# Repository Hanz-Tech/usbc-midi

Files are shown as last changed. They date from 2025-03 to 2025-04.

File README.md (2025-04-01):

# Portable USB-MIDI-CV Converter

Ultraportable device for converting MIDI between various hardware standard

Allows you to convert signal between MIDI USB Device, MIDI USB host, MIDI TRS and CV.

## Features
* 1x1 MIDI TRS interface
* Tiny footprint (3cm x 3cm x 1cm)
* USB-C powered
* MIDI USB-MIDI compliant Device
* Plug and play - no drivers needed
* Can act USB host for USB MIDI keyboards, synths....
* Optoisolated TRS MIDI input
* Buffered TRS MIDI output
* CV (0-5 V)
* Powered by RP2040

## Photos

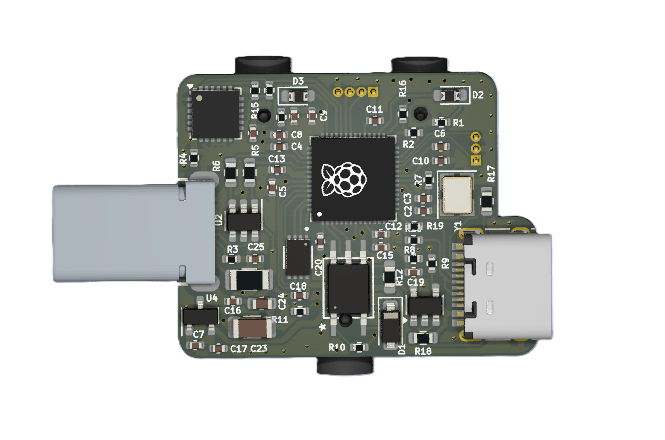
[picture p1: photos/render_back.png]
render


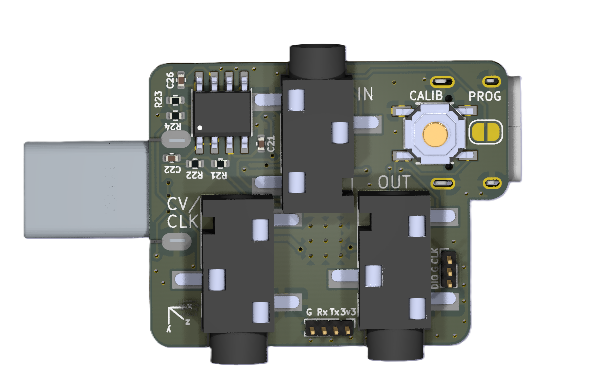
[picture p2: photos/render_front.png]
render


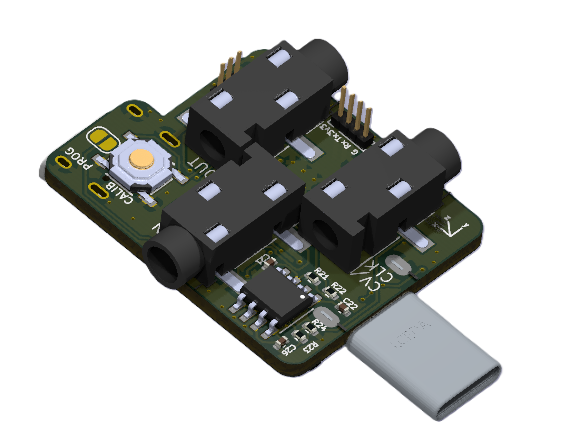
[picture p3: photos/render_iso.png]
render


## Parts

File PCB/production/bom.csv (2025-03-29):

Designator | Footprint | Quantity | Value | LCSC Part #
C1, C10, C11, C12, C13, C14, C15, C18, C25, C5, C6, C9 | 0402 | 12 | 100nF | C1525
C16, C17, C4, C8 | 0402 | 4 | 1uF | C52923
C19, C20, C26 | 0402 | 3 | 0.1uF | C1525
C2, C3 | 0402 | 2 | 22pF | C1555
C21, C22 | 0402 | 2 | 1nF | C1523
C23 | 1206 | 1 | 100uF | C15008
C24 | 0603 | 1 | 10uF | C19702
C7 | 0402 | 1 | 10uF | C15525
D1 | D_SOD-123 | 1 | 1N4148W | C81598
D2, D3 | 0603 | 2 | LED | C2286
F1 | 1206 | 1 | 500mA | C70077
J2 | PinHeader_1x03_P1.00mm_Vertical | 1 | 640456-3 | 640456-3
J5 | PinHeader_1x04_P1.00mm_Vertical | 1 | B4B-PH-K-S_LF__SN_ | B4B-PH-K-S(LF)(SN)
J6 | USB_C_Receptacle_HRO_TYPE-C-31-M-12 | 1 | USB_C_Receptacle_USB2.0_14P | C165948
R1, R10, R13, R8, R9 | 0402 | 5 | 220 | C25091
R11, R7 | 0402 | 2 | 1k | C11702
R12 | 0603 | 1 | 470 | C17710
R14, R15, R23, R3, R4 | 0402 | 5 | 5k1 | C25905
R16, R2, R24 | 0402 | 3 | 10k | C25744
R17, R18 | 0603 | 2 | 56k | C23206
R19, R20 | 0402 | 2 | 22 | C25092
R21, R22 | 0402 | 2 | 16k | C25759
R5, R6 | 0603 | 2 | 27R | C25190
S1 | TACTILE_SWITCH_SMD_5.2MM | 1 | TS-1187A-B-A-B | C318884
U1 | InvenSense_QFN-24_4x4mm_P0.5mm | 1 | MPU-6050 | C24112
U2 | SOT-23-6 | 1 | USBLC6-2SC6 | C2827654
U3 | RP2040-QFN-56 | 1 | RP2040 | C2040
U4 | SOT-23 | 1 | XC6206PxxxMR-Regulator_Linear | C5446
U5 | SOT-23-5 | 1 | SN74LVC1G07DBVR | C7829
U6 | W25Q16JVUXIQ | 1 | W25Q16JVUXIQ TR | C2843335
U7 | tlp2362 | 1 | TLP2362TPR_E | C37658
U8 | SOIC127P599X175-8N | 1 | OPA2335AIDR | C41618
UNK1 | USB-C-SMD_XKB_U261-24XN-4BC2SS | 1 | USB-C-SMD_XKB_U261-24XN-4BC2SS | C2938597
Y1 | Crystal_SMD_3225-4Pin_3.2x2.5mm | 1 | 12MHz | C9002

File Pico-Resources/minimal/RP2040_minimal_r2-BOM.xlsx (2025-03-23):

RP2040_minimal_r2 BOM
Item | Quantity | Reference | Part | Voltage | Current | Power | Material | Size | Tolerance | Manufacturer | Manuf. Part # | Description | Notes
1 | 3 | C1,C4,C17 | 10u | 16V |  |  | X5R | 0805_2012Metric | 10% | Murata | GRM21BR61C106KE15K | CAP CER 10UF 16V X5R 0805 | Or equivalent
2 | 2 | C2, C3 | 15p | 50V |  |  | C0G | 0402_1005Metric | 5% | Murata | GCM1555C1H150JA16D | CAP CER 15PF 50V C0G/NP0 0402 | Or equivalent
3 | 10 | C5, C6, C7, C9, C11, C12, C13, C14, C15, C16 | 100n | 25V |  |  | X7R | 0402_1005Metric | 10% | Murata | GRM155R71E104KE14J | CAP CER 0.1UF 25V X7R 0402 | Or equivalent
4 | 2 | C8, C10 | 1u | 10V |  |  | X6S | 0402_1005Metric | 10% | Murata | GRM155C81A105KA12D | CAP CER 1UF 10V X6S 0402 | Or equivalent
5 | 1 | J1 | USB_B_Micro |  |  |  |  |  |  | Amphenol | 10103594-0001LF | CONN RCPT USB2.0 MICRO B SMD R/A | Or equivalent
6 | 1 | J2 | 1x2 way header |  |  |  |  |  |  | Samtec | TSW-102-23-T-S | 2.54mm pin header 1x2 | Or equivalent
7 | 2 | J3, J4 | 2x18 way header |  |  |  |  |  |  | Samtec | TSW-118-23-T-D | 2.54mm pin header 2x18 | Or equivalent
8 | 2 | R1, R5 | 1k |  |  | 63mW |  | 0402_1005Metric | 1% | Yageo | RC0402FR-071KP | RES SMD 1K OHM 1% 1/16W 0402 | Or equivalent
9 | 1 | R2 | DNF |  |  |  |  | 0402_1005Metric |  |  |  |  | Do Not Fit
10 | 2 | R3, R4 | 27.4 |  |  | 63mW |  | 0402_1005Metric | 1% | Yageo | RC0402FR-0727R4L | RES SMD 27.4 OHM 1% 1/16W 0402 | Or equivalent
11 | 1 | U1 | NCP1117-3.3 |  |  |  |  | SOT-223-3 |  | ON Semiconductor | NCP1117ST33T3G | IC REG LINEAR 3.3V 1A SOT223
12 | 1 | U2 | W25Q128JVS |  |  |  |  | SOIC-8 |  | Winbond | W25Q128JVSIQ TR | IC FLASH 128M SPI 133MHZ 8SOIC
13 | 1 | U3 | RP2040 |  |  |  |  | QFN56 |  | Raspberry Pi | RP2040
14 | 1 | Y1 | ABM8-272-T3 |  |  |  |  | SMD_3225 |  | Abracon | ABM8-272-T3 | CRYSTAL 12.0000MHZ 3.2x2.5MM SMD

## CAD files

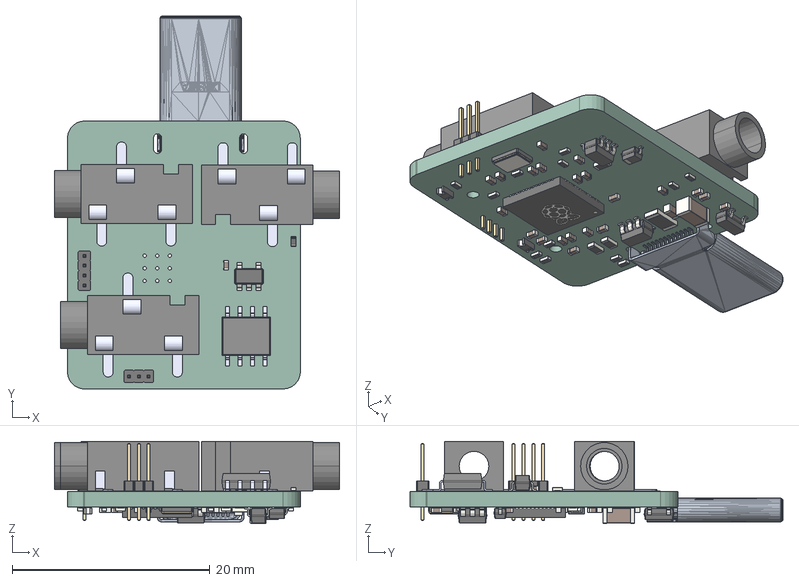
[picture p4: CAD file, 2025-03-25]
PCB/usbc_midi.step
28.9 x 37.7 x 8.30 mm
SOT_23_5 x 2
R_0402_1005Metric x 13
PinHeader_1x03_P100mm_Vertical
PJ-320B x 3
PinHeader_1x04_P100mm_Vertical
C_0402_1005Metric x 22
MCP6242T-E_SN
D_0603 x 2
SOT_23
R_0603_1608Metric x 3
C_1206_3216Metric
SOT_23_6
D_SOD_323
C_0603_1608Metric
Fuse_1206_3216Metric
RP2040_QFN_PACKAGE
Crystal_SMD_3225-4Pin_3.2x2.5mm
USB_C_SMD_XKB_U261_24XN_4BC2SS001
_autosave-usbc_midi_PCB

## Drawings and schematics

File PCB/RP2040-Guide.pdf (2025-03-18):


1 GPIO8 11 GPIO9 12 GPIO10 13 GPIO11 14 GPIO12 15 GPIO13 16 GPIO14 17 GPIO15 18 TESTEN 19 GPIO0 2 XTAL_IN 20 XTAL_OUT 21 SWCLK 24 SWDIO 25 ~{RUN} 26 GPIO16 27 GPIO17 28 GPIO18 29 GPIO1 3 GPIO19 30 GPIO20 31 GPIO21 32 GPIO22 34 GPIO23 35 GPIO24 36 GPIO25 37 GPIO26/ADC0 38 GPIO27/ADC1 39 GPIO2 4 GPIO28/ADC2 40 GPIO29/ADC3 41 ADC_AVDD 43 VREG_VIN 44 VREG_VOUT 45 D- 46 D+ 47 USB_VDD 48 GPIO3 5 DVDD 50 QSPI_SD3 51 QSPI_SCLK 52 QSPI_SD0 53 QSPI_SD2 54 QSPI_SD1 55 QSPI_SS_N 56 GND 57 GPIO4 6 GPIO5 7 GPIO6 8 GPIO7 9 U3 GND RP2040 +3.3V C6

File: RP2040-Guide.kicad_sch Sheet: / Sleepdealer

Id: 1/1 Title: RP2040 - Design Guide

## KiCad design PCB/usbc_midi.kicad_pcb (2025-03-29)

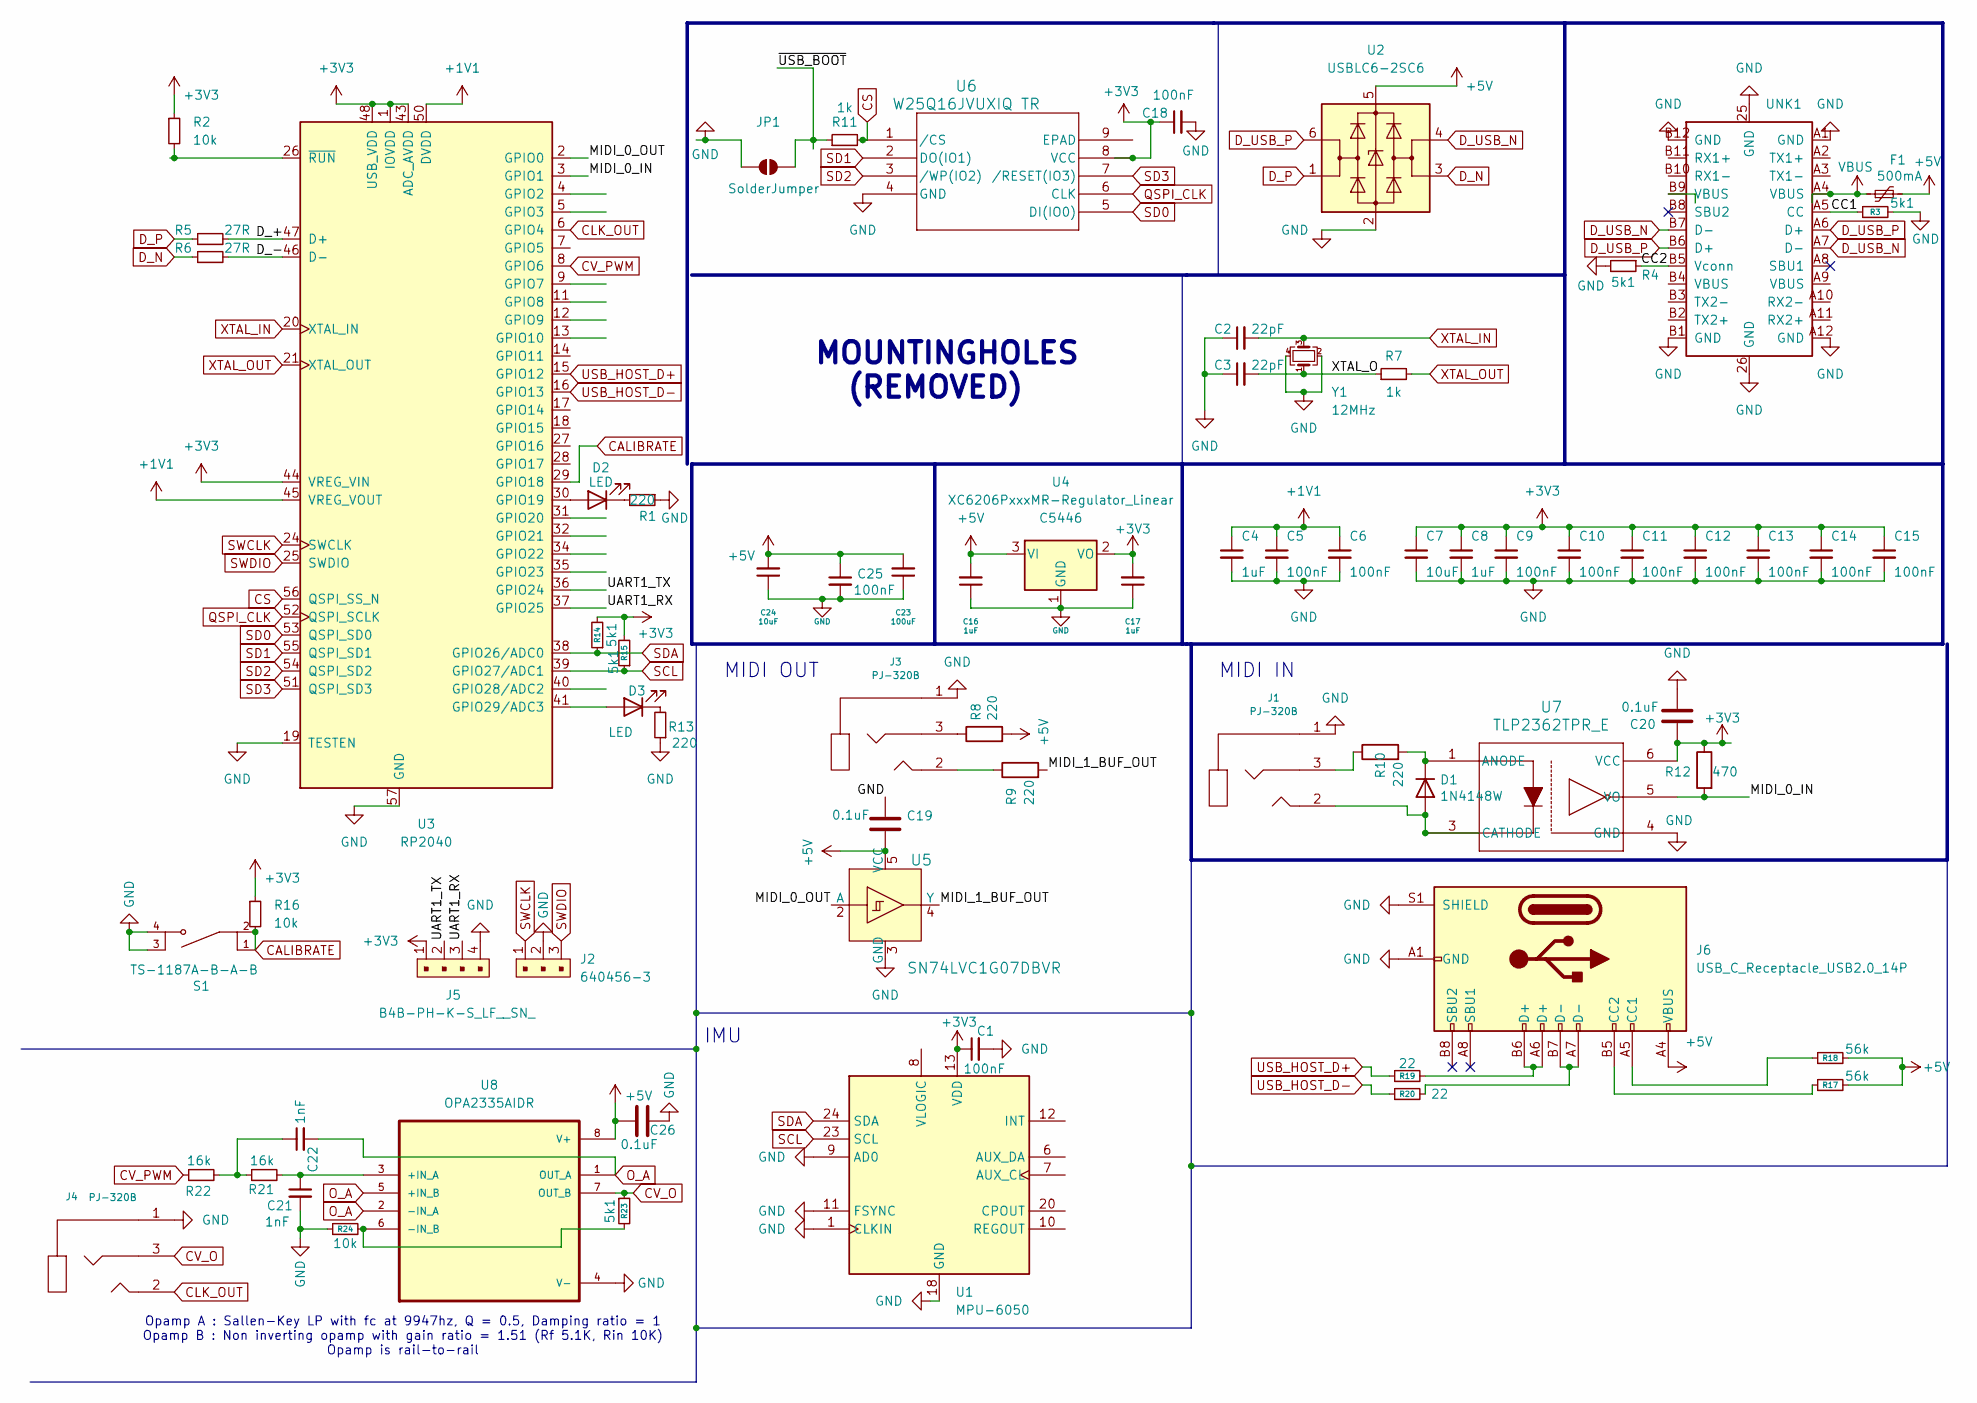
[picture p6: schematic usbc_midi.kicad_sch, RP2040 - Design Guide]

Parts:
C1, C5, C6, C9, C10, C11, C12, C13, C14, C15, C18, C25: 100nF; C_0402_1005Metric; LCSC C1525
C2, C3: 22pF; C_0402_1005Metric; LCSC C1555
C4, C8, C16, C17: 1uF; C_0402_1005Metric; LCSC C52923
C7: 10uF; C_0402_1005Metric; LCSC C15525
C19, C20, C26: 0.1uF; C_0402_1005Metric; LCSC C1525
C21, C22: 1nF; C_0402_1005Metric; LCSC C1523
C23: 100uF; C_1206_3216Metric; LCSC C15008
C24: 10uF; C_0603_1608Metric; LCSC C19702
D1: 1N4148W; D_SOD-123; LCSC C81598
D2, D3: LED; D_0603_1608Metric_Pad1.05x0.95mm_HandSolder; LCSC C2286
F1: 500mA; Fuse_1206_3216Metric; LCSC C70077
J1, J3, J4: PJ-320B; 3.5mm_stereo_jack_PJ320B_no_back_hole; LCSC C2884998
J2: 640456-3; PinHeader_1x03_P1.00mm_Vertical; MPN 640456-3; Digi-Key_PN A19470-ND
J5: B4B-PH-K-S_LF__SN_; PinHeader_1x04_P1.00mm_Vertical; MPN B4B-PH-K-S(LF)(SN); Digi-Key_PN 455-1706-ND
J6: USB_C_Receptacle_USB2.0_14P; USB_C_Receptacle_HRO_TYPE-C-31-M-12; LCSC C165948
JP1: SolderJumper; SolderJumper-2_P1.3mm_Open_RoundedPad1.0x1.5mm
R1, R8, R9, R10, R13: 220; R_0402_1005Metric; LCSC C25091
R2, R16, R24: 10k; R_0402_1005Metric; LCSC C25744
R3, R4, R14, R15, R23: 5k1; R_0402_1005Metric; LCSC C25905
R5, R6: 27R; R_0603_1608Metric; LCSC C25190
R7, R11: 1k; R_0402_1005Metric; LCSC C11702
R12: 470; R_0603_1608Metric_Pad0.98x0.95mm_HandSolder; LCSC C17710
R17, R18: 56k; R_0603_1608Metric; LCSC C23206
R19, R20: 22; R_0402_1005Metric; LCSC C25092
R21, R22: 16k; R_0402_1005Metric; LCSC C25759
S1: TS-1187A-B-A-B; TACTILE_SWITCH_SMD_5.2MM; PARTREV A0; LCSC C318884
U1: MPU-6050; InvenSense_QFN-24_4x4mm_P0.5mm; LCSC C24112
U2: USBLC6-2SC6; SOT-23-6; LCSC C2827654
U3: RP2040; RP2040-QFN-56; LCSC C2040
U4: XC6206PxxxMR-Regulator_Linear; SOT-23; LCSC C5446
U5: SN74LVC1G07DBVR; SOT-23-5; Digi-Key_PN 296-8485-1-ND
U6: W25Q16JVUXIQ TR; W25Q16JVUXIQ; LCSC C2843335
U7: TLP2362TPR_E; tlp2362; LCSC C37658
U8: OPA2335AIDR; SOIC127P599X175-8N; LCSC C41618
UNK1: USB-C-SMD_XKB_U261-24XN-4BC2SS; LCSC C2938597
Y1: 12MHz; Crystal_SMD_3225-4Pin_3.2x2.5mm; LCSC C9002

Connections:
+1V1: C4.1, C5.1, C6.1, U3.23 (DVDD), U3.45 (VREG_VOUT), U3.50 (DVDD)
+3V3: C1.1, C7.1, C8.1, C9.1, C10.1, C11.1, C12.1, C13.1, C14.1, C15.1, C17.2, C18.1, C20.1, J5.1, R2.1, R12.1, R14.2, R15.2, R16.1, U1.13 (VDD), U3.1 (IOVDD), U3.10 (IOVDD), U3.22 (IOVDD), U3.33 (IOVDD), U3.42 (IOVDD), U3.43 (ADC_AVDD), U3.44 (VREG_VIN), U3.48 (USB_VDD), U3.49 (IOVDD), U4.2 (VO), U6.8 (VCC), U7.6 (VCC)
+5V: C16.2, C19.2, C23.2, C24.2, C25.1, C26.1, F1.2, J6.A4 (VBUS), J6.A9 (VBUS), J6.B4 (VBUS), J6.B9 (VBUS), R8.2, R17.2, R18.2, U2.5 (VBUS), U4.3 (VI), U5.5 (VCC), U8.8 (V+)
/CC1: R3.1, UNK1.A5 (CC)
/CC2: R4.1, UNK1.B5 (Vconn)
/D_+: R5.2, U3.47 (D+)
/D_-: R6.2, U3.46 (D-)
/MIDI_0_IN: R12.2, U3.3 (GPIO1), U7.5 (VO)
/MIDI_0_OUT: U3.2 (GPIO0), U5.2 (A)
/MIDI_1_BUF_OUT: R9.2, U5.4 (Y)
/UART1_RX: J5.3, U3.37 (GPIO25)
/UART1_TX: J5.2, U3.36 (GPIO24)
/XTAL_O: C3.2, R7.1, Y1.1
/~USB_BOOT: JP1.2 (B), R11.1
CALIBRATE: R16.2, S1.1, S1.2, U3.29 (GPIO18)
CLK_OUT: J4.2, U3.6 (GPIO4)
CS: R11.2, U3.56 (QSPI_SS_N), U6.1 (/CS)
CV_O: J4.3, R23.1, U8.7 (OUT_B)
CV_PWM: R22.1, U3.8 (GPIO6)
D_N: R6.1, U2.3 (I/O2)
D_P: R5.1, U2.1 (I/O1)
D_USB_N: U2.4 (I/O2), UNK1.A7 (D-), UNK1.B7 (D-)
D_USB_P: U2.6 (I/O1), UNK1.A6 (D+), UNK1.B6 (D+)
GND: C1.2, C2.1, C3.1, C4.2, C5.2, C6.2, C7.2, C8.2, C9.2, C10.2, C11.2, C12.2, C13.2, C14.2, C15.2, C16.1, C17.1, C18.2, C19.1, C20.2, C21.2, C23.1, C24.1, C25.2, C26.2, J1.1, J2.2, J3.1, J4.1, J5.4, J6.A1 (GND), J6.A12 (GND), J6.B1 (GND), J6.B12 (GND), J6.S1 (SHIELD), JP1.1 (A), R1.1, R3.2, R4.2, R13.1, R24.1, S1.3, S1.4, U1.1 (CLKIN), U1.9 (AD0), U1.11 (FSYNC), U1.18 (GND), U2.2 (GND), U3.19 (TESTEN), U3.57 (GND), U4.1 (GND), U5.3 (GND), U6.4 (GND), U7.4 (GND), U8.4 (V-), UNK1.25 (GND), UNK1.26 (GND), UNK1.A1 (GND), UNK1.A12 (GND), UNK1.B1 (GND), UNK1.B12 (GND), Y1.2, Y1.4
unnamed: C22.1, R21.1, R22.2
unnamed: D1.2 (A), J1.2, U7.3 (CATHODE)
unnamed: D1.1 (K), R10.2, U7.1 (ANODE)
unnamed: D2.2 (A), U3.30 (GPIO19)
unnamed: D2.1 (K), R1.2
unnamed: D3.2 (A), U3.41 (GPIO29/ADC3)
unnamed: D3.1 (K), R13.2
unnamed: J1.3, R10.1
unnamed: J3.2, R9.1
unnamed: J3.3, R8.1
unnamed: J6.A5 (CC1), R18.1
unnamed: J6.B5 (CC2), R17.1
unnamed: J6.A6 (D+), J6.B6 (D+), R19.2
unnamed: J6.A7 (D-), J6.B7 (D-), R20.2
unnamed: R2.2, U3.26 (~RUN)
unnamed: C21.1, R21.2, U8.3 (+IN_A)
unnamed: R23.2, R24.2, U8.6 (-IN_B)
O_A: C22.2, U8.1 (OUT_A), U8.2 (-IN_A), U8.5 (+IN_B)
QSPI_CLK: U3.52 (QSPI_SCLK), U6.6 (CLK)
SCL: R15.1, U1.23 (SCL), U3.39 (GPIO27/ADC1)
SD0: U3.53 (QSPI_SD0), U6.5 (DI(IO0))
SD1: U3.55 (QSPI_SD1), U6.2 (DO(IO1))
SD2: U3.54 (QSPI_SD2), U6.3 (/WP(IO2))
SD3: U3.51 (QSPI_SD3), U6.7 (/RESET(IO3))
SDA: R14.1, U1.24 (SDA), U3.38 (GPIO26/ADC0)
SWCLK: J2.1, U3.24 (SWCLK)
SWDIO: J2.3, U3.25 (SWDIO)
USB_HOST_D+: R19.1, U3.15 (GPIO12)
USB_HOST_D-: R20.1, U3.16 (GPIO13)
VBUS: F1.1, UNK1.A4 (VBUS)
XTAL_IN: C2.2, U3.20 (XTAL_IN), Y1.3
XTAL_OUT: R7.2, U3.21 (XTAL_OUT)

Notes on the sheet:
MIDI IN
Opamp A : Sallen-Key LP with fc at 9947hz, Q = 0.5, Damping ratio = 1 Opamp B : Non inverting opamp with gain ratio = 1.51 (Rf 5.1K, Rin 10K) Opamp is rail-to-rail
MOUNTINGHOLES (REMOVED)
MIDI OUT
IMU

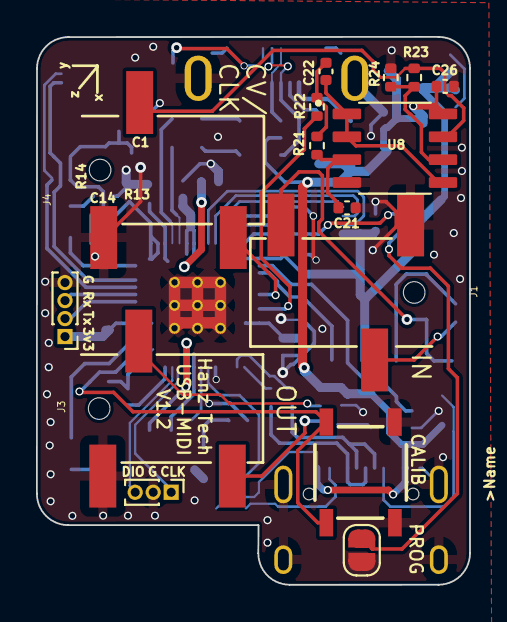
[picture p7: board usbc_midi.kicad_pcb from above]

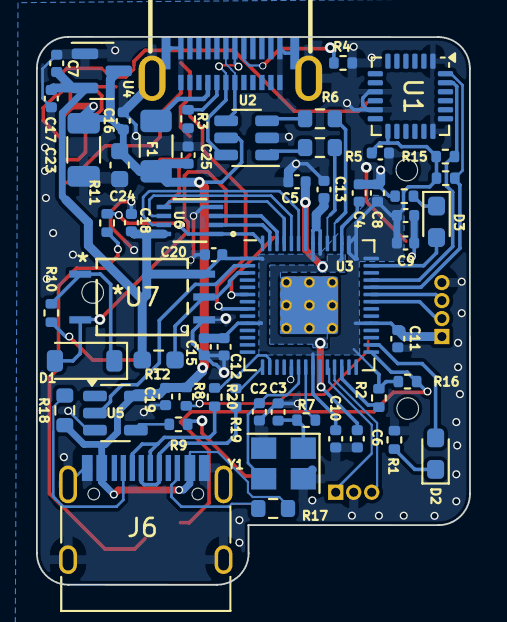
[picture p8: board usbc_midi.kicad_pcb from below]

Board: 2 copper layers, 24.1 x 30.4 mm, 72 parts (57 on the bottom side), 56 nets.

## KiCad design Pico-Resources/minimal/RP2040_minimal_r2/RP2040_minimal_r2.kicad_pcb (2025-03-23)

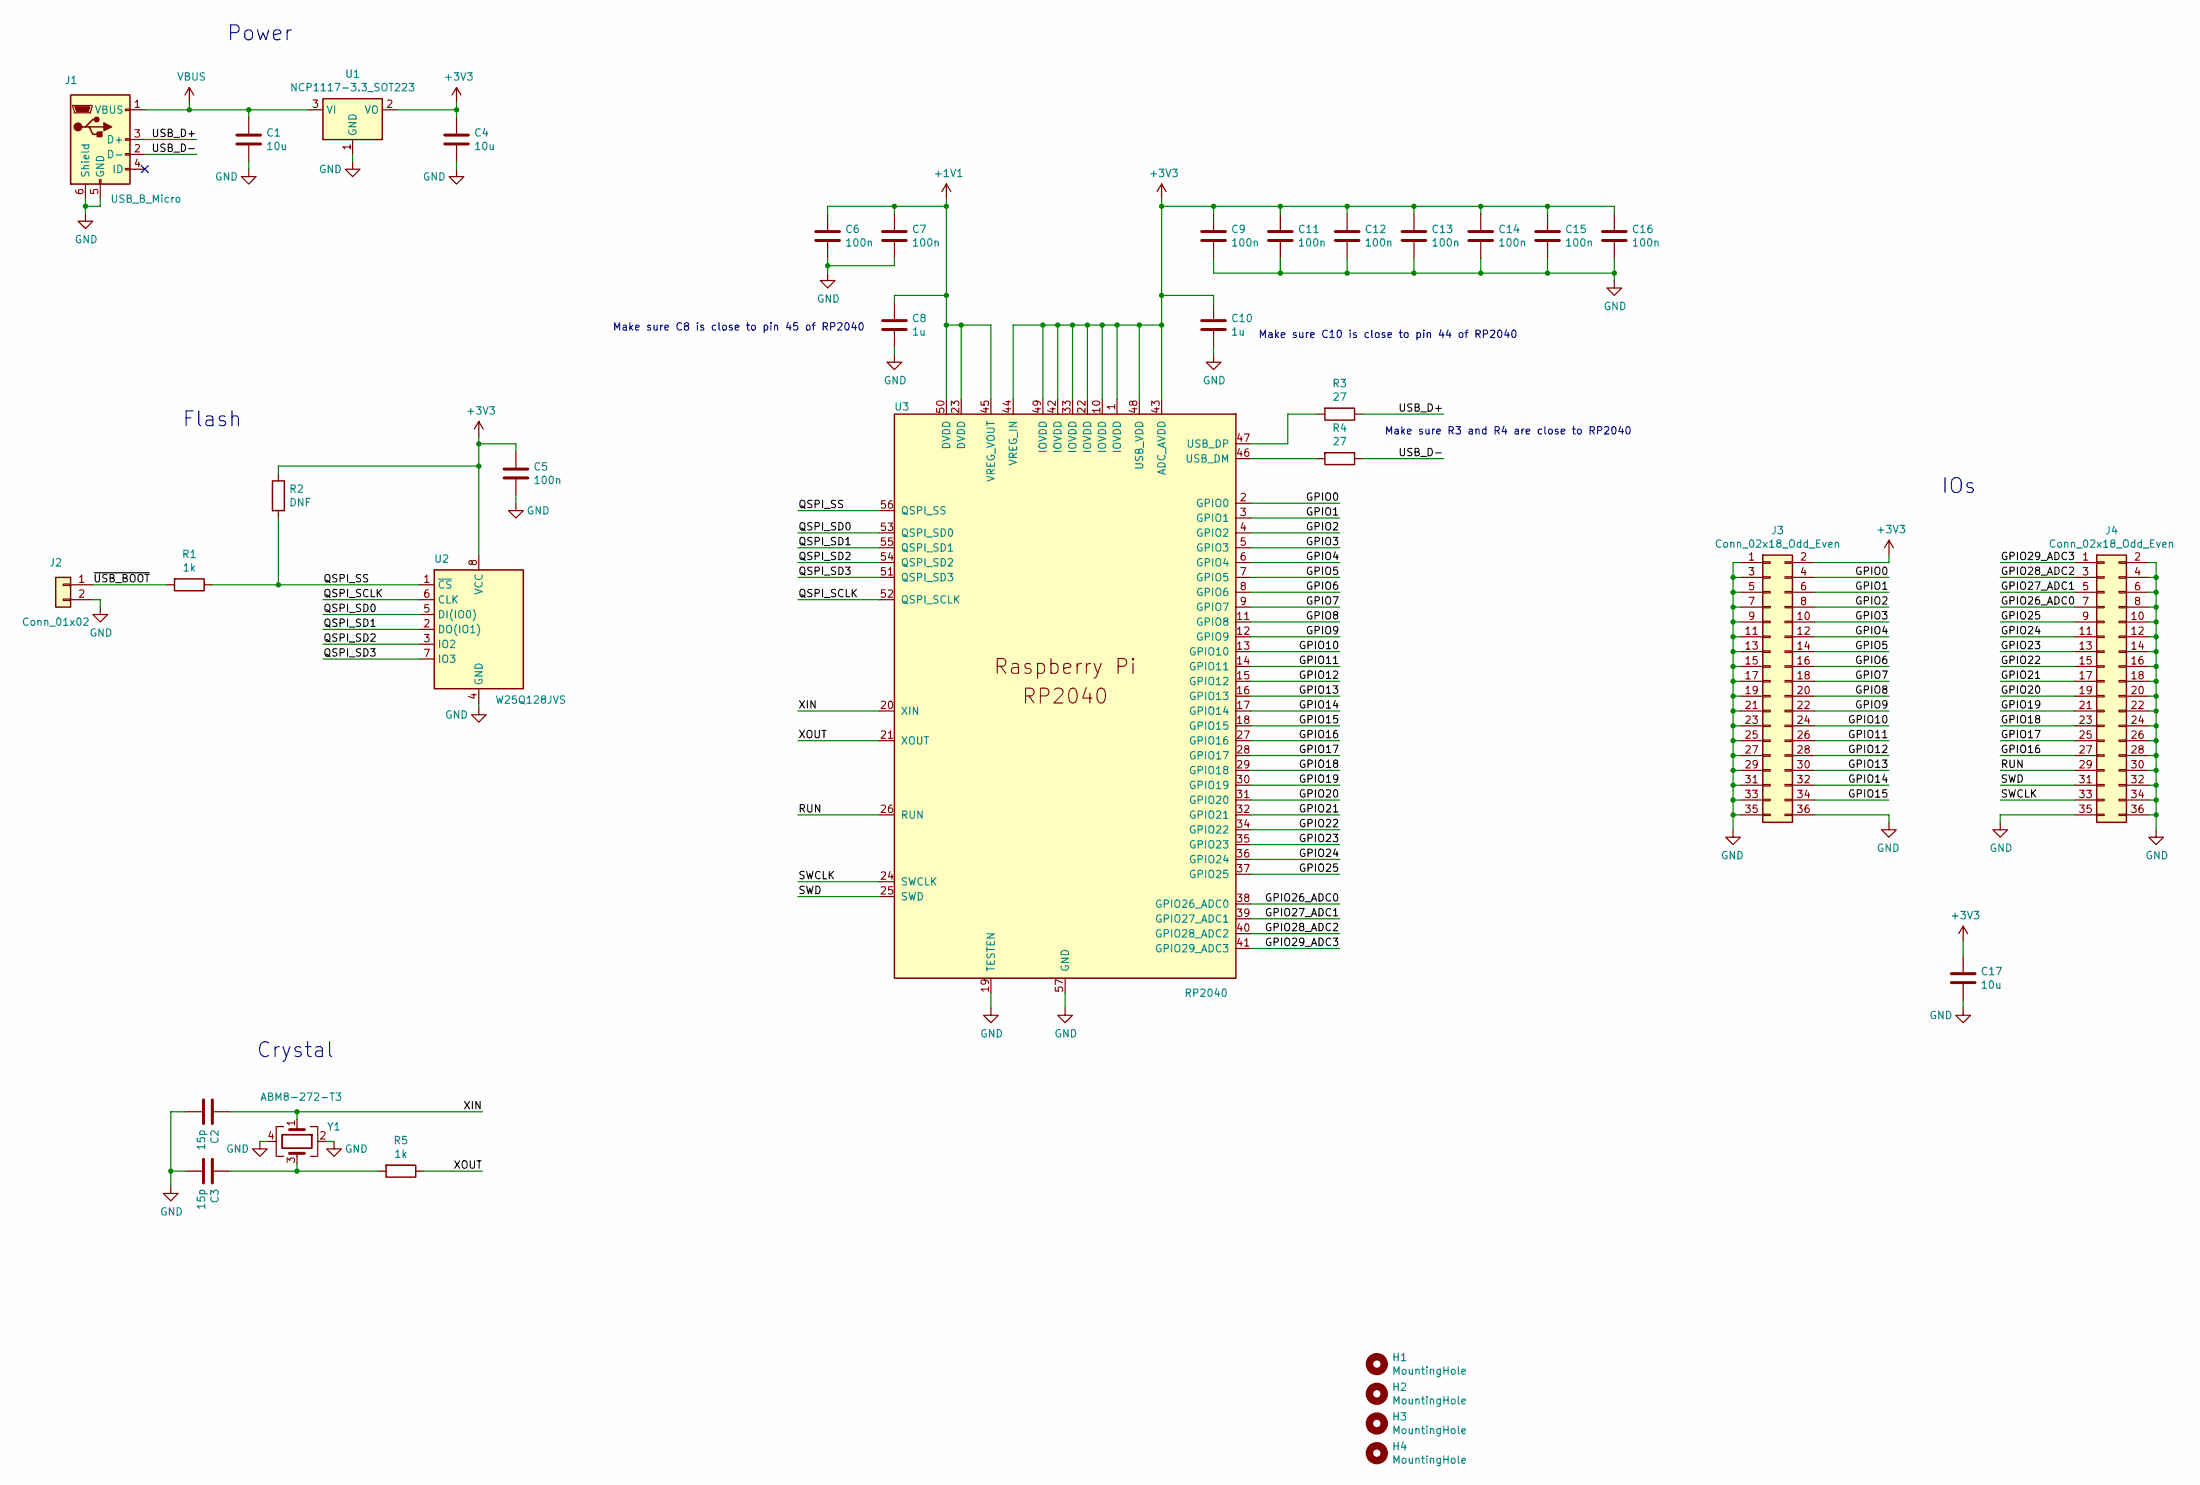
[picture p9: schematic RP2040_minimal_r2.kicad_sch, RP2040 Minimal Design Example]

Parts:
C1, C4, C17: 10u; C_0805_2012Metric
C2, C3: 15p; C_0402_1005Metric
C5, C6, C7, C9, C11, C12, C13, C14, C15, C16: 100n; C_0402_1005Metric
C8, C10: 1u; C_0402_1005Metric
H1, H2, H3, H4: MountingHole; MountingHole_2.7mm_M2.5
J1: USB_B_Micro; USB_Micro-B_Amphenol_10103594-0001LF_Horizontal_modified
J2: Conn_01x02; PinHeader_1x02_P2.54mm_Vertical
J3, J4: Conn_02x18_Odd_Even; PinHeader_2x18_P2.54mm_Vertical
R1, R5: 1k; R_0402_1005Metric
R2: DNF; R_0402_1005Metric
R3, R4: 27; R_0402_1005Metric
U1: NCP1117-3.3_SOT223; SOT-223-3_TabPin2
U2: W25Q128JVS; SOIC-8_5.23x5.23mm_P1.27mm
U3: RP2040; RP2040-QFN-56
Y1: ABM8-272-T3; Crystal_SMD_3225-4Pin_3.2x2.5mm

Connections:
+1V1: C6.1, C7.1, C8.1, U3.23 (DVDD), U3.45 (VREG_VOUT), U3.50 (DVDD)
+3V3: C4.1, C5.1, C9.1, C10.1, C11.1, C12.1, C13.1, C14.1, C15.1, C16.1, C17.1, J3.2, R2.1, U1.2 (VO), U2.8 (VCC), U3.1 (IOVDD), U3.10 (IOVDD), U3.22 (IOVDD), U3.33 (IOVDD), U3.42 (IOVDD), U3.43 (ADC_AVDD), U3.44 (VREG_IN), U3.48 (USB_VDD), U3.49 (IOVDD)
/GPIO0: J3.4, U3.2 (GPIO0)
/GPIO1: J3.6, U3.3 (GPIO1)
/GPIO2: J3.8, U3.4 (GPIO2)
/GPIO3: J3.10, U3.5 (GPIO3)
/GPIO4: J3.12, U3.6 (GPIO4)
/GPIO5: J3.14, U3.7 (GPIO5)
/GPIO6: J3.16, U3.8 (GPIO6)
/GPIO7: J3.18, U3.9 (GPIO7)
/GPIO8: J3.20, U3.11 (GPIO8)
/GPIO9: J3.22, U3.12 (GPIO9)
/GPIO10: J3.24, U3.13 (GPIO10)
/GPIO11: J3.26, U3.14 (GPIO11)
/GPIO12: J3.28, U3.15 (GPIO12)
/GPIO13: J3.30, U3.16 (GPIO13)
/GPIO14: J3.32, U3.17 (GPIO14)
/GPIO15: J3.34, U3.18 (GPIO15)
/GPIO16: J4.27, U3.27 (GPIO16)
/GPIO17: J4.25, U3.28 (GPIO17)
/GPIO18: J4.23, U3.29 (GPIO18)
/GPIO19: J4.21, U3.30 (GPIO19)
/GPIO20: J4.19, U3.31 (GPIO20)
/GPIO21: J4.17, U3.32 (GPIO21)
/GPIO22: J4.15, U3.34 (GPIO22)
/GPIO23: J4.13, U3.35 (GPIO23)
/GPIO24: J4.11, U3.36 (GPIO24)
/GPIO25: J4.9, U3.37 (GPIO25)
/GPIO26_ADC0: J4.7, U3.38 (GPIO26_ADC0)
/GPIO27_ADC1: J4.5, U3.39 (GPIO27_ADC1)
/GPIO28_ADC2: J4.3, U3.40 (GPIO28_ADC2)
/GPIO29_ADC3: J4.1, U3.41 (GPIO29_ADC3)
/QSPI_SCLK: U2.6 (CLK), U3.52 (QSPI_SCLK)
/QSPI_SD0: U2.5 (DI(IO0)), U3.53 (QSPI_SD0)
/QSPI_SD1: U2.2 (DO(IO1)), U3.55 (QSPI_SD1)
/QSPI_SD2: U2.3 (IO2), U3.54 (QSPI_SD2)
/QSPI_SD3: U2.7 (IO3), U3.51 (QSPI_SD3)
/QSPI_SS: R1.1, R2.2, U2.1 (~CS), U3.56 (QSPI_SS)
/RUN: J4.29, U3.26 (RUN)
/SWCLK: J4.33, U3.24 (SWCLK)
/SWD: J4.31, U3.25 (SWD)
/USB_D+: J1.3 (D+), R3.1
/USB_D-: J1.2 (D-), R4.1
/XIN: C2.1, U3.20 (XIN), Y1.1
/XOUT: R5.1, U3.21 (XOUT)
/~USB_BOOT: J2.1, R1.2
GND: C1.2, C2.2, C3.2, C4.2, C5.2, C6.2, C7.2, C8.2, C9.2, C10.2, C11.2, C12.2, C13.2, C14.2, C15.2, C16.2, C17.2, J1.5 (GND), J1.6 (Shield), J2.2, J3.1, J3.3, J3.5, J3.7, J3.9, J3.11, J3.13, J3.15, J3.17, J3.19, J3.21, J3.23, J3.25, J3.27, J3.29, J3.31, J3.33, J3.35, J3.36, J4.2, J4.4, J4.6, J4.8, J4.10, J4.12, J4.14, J4.16, J4.18, J4.20, J4.22, J4.24, J4.26, J4.28, J4.30, J4.32, J4.34, J4.35, J4.36, U1.1 (GND), U2.4 (GND), U3.19 (TESTEN), U3.57 (GND), Y1.2, Y1.4
unnamed: C3.1, R5.2, Y1.3
unnamed: R4.2, U3.46 (USB_DM)
unnamed: R3.2, U3.47 (USB_DP)
VBUS: C1.1, J1.1 (VBUS), U1.3 (VI)

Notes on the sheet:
IOs
Power
Crystal
Make sure C8 is close to pin 45 of RP2040
Make sure C10 is close to pin 44 of RP2040
Make sure R3 and R4 are close to RP2040
Flash


Board: 2 copper layers, 52.0 x 51.0 mm, 34 parts (0 on the bottom side), 51 nets.

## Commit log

2025-03-20 routing in progress
    [RP2040-Guide.kicad_pcb, RP2040-Guide.kicad_sch, usbc_midi.kicad_pcb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]
2025-03-20 update routing
    [usbc_midi.kicad_pcb]
2025-03-21 finished 1st layout
    [usbc_midi.kicad_pcb, usbc_midi.kicad_sch]
2025-03-21 fix silkscreen
    [usbc_midi.kicad_pcb]
2025-03-21 add logo
    [usbc_midi.kicad_pcb, usbc_midi.kicad_sch]
2025-03-22 ready v1
    [bom.csv, designators.csv, positions.csv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]
2025-03-22 export v1.0
    [bom.csv, designators.csv, positions.csv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]
2025-03-25 added layout for cv control
    [bom.csv, designators.csv, positions.csv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]
2025-03-26 fix some routing errors
    [bom.csv, positions.csv, usbc_midi.kicad_pcb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]
2025-03-28 1.2 added usb host
    [bom.csv, designators.csv, positions.csv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]
2025-03-29 1.2 sent to production
    [bom.csv, designators.csv, positions.csv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]
